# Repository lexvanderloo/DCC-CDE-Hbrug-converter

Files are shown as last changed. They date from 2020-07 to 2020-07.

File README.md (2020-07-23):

# CDE-Hbrug-converter-DCC-
Stuurt een DCC-gebaseerd CDE-signaal naar een Hbrug. Vormt daarmee een goedkope Booster voor DCC

LET OP: NOG NIET GETEST
V11 is zojuist terug van de printfabriek en wordt binnenkort getest.

De bestanden zijn voor Kicad v5

Aan de CDE-kant wort het CDE-signaal van een centrale aangesloten
Daarnaast een DC-voeding van maximaal 18V
Aan de Hbrug-kant worden de +5V en GND op de Hbrug aangesloten. 
Daarnaast de RPW en de LPW. De beide Kortsluitmeldingen IS-left en IS-right van de Hbrug worden beide op IS aangesloten.
De CDE-signalen zijn galvanisch geschieden van de Hbrug.
U4 zorgt voor een constante spanning van 5V voor de elektronica.
De vermogensstroom voor de Hbrug komt van een aparte bron.

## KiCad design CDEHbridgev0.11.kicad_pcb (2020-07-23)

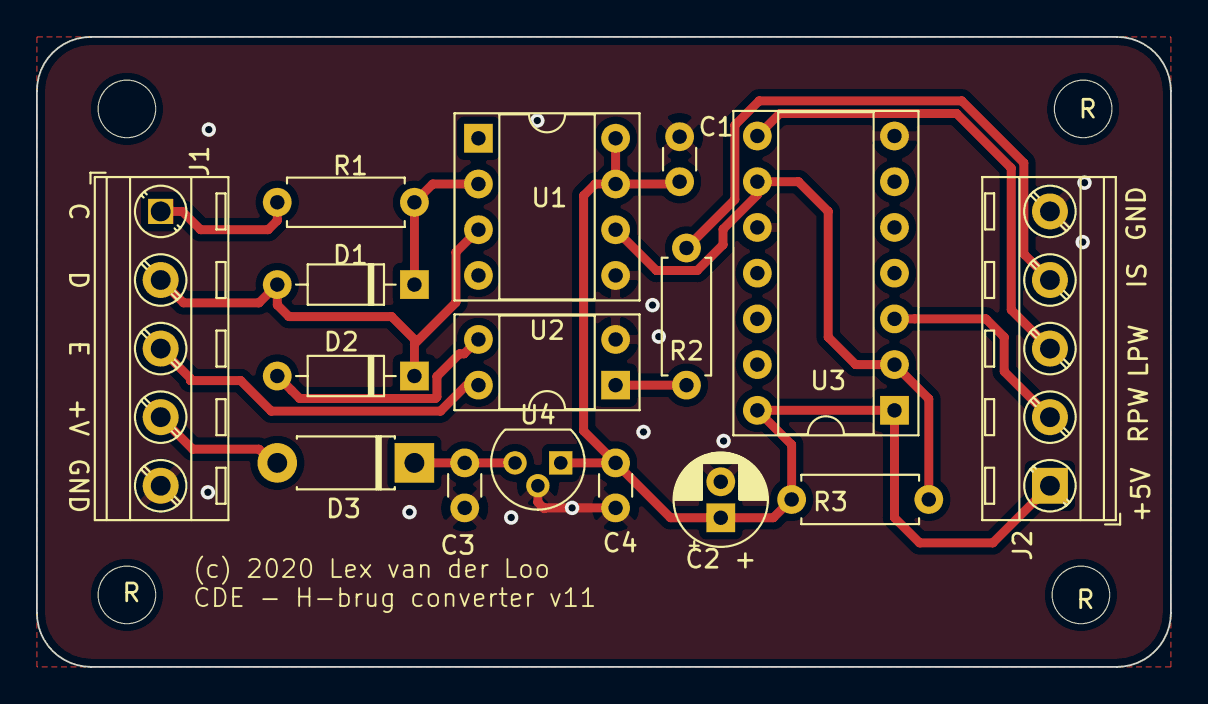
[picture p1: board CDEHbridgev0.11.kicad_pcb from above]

Board: 2 copper layers, 63.0 x 35.0 mm, 20 parts (0 on the bottom side), 14 nets.

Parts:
C1, C3, C4: 100n; C_Disc_D3.0mm_W1.6mm_P2.50mm
C2 +: 10u; CP_Radial_D5.0mm_P2.00mm
D1, D2: 4148; D_DO-35_SOD27_P7.62mm_Horizontal
D3: 4004; D_DO-41_SOD81_P7.62mm_Horizontal
J1, J2: S; TerminalBlock_MetzConnect_Type086_RT03405HBLC_1x05_P3.81mm_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
R: 3.2mm; MountingHole_3.2mm_M3_DIN965
R1: 2k2; R_Axial_DIN0207_L6.3mm_D2.5mm_P7.62mm_Horizontal
R2, R3: 1k; R_Axial_DIN0207_L6.3mm_D2.5mm_P7.62mm_Horizontal
R#2, R#3, R#4: 3.2mm; MountingHole_3.2mm_M3_DIN965
U1: 6N137; DIP-8_W7.62mm_Socket
U2: TLP785; DIP-4_W7.62mm_Socket
U3: 74LS86; DIP-14_W7.62mm_Socket
U4: LM78L05; TO-92

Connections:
+5V: C1.1, C2 +.1, C4.1, J2.1, R3.1, U1.7, U1.8, U3.1, U3.14, U4.1
/+Voeding: D3.2, J1.4
/C: J1.1, R1.2
/D: D1.2, D2.1, J1.2, U1.3
/E: J1.3, U2.4
/LPWM: J2.3, U3.8
/RPWM: J2.2, U3.3
/R_ISenL_IS: J2.4, R2.1
GND: C1.2, C2 +.2, C3.2, C4.2, J1.5, J2.5, U1.5, U2.2, U3.7, U3.10, U4.2
unnamed: C3.1, D3.1, U4.3
unnamed: D1.1, R1.1, U1.2
unnamed: D2.2, U2.3
unnamed: R2.2, U2.1
unnamed: R3.2, U1.6, U3.2, U3.9

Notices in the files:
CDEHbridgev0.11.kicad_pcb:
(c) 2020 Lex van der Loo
